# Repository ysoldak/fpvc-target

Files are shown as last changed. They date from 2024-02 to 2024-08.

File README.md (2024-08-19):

# FPVCombat Ground Target and Test Station

Turn your FPV Combat board, sensor and gun to a nice ground target and a reliable test station!  
You'll need [FPV Combat kit](https://fpv-combat.com/) and some other parts, full list below.  
Bottom plate has holes for easy mount on any standard camera tripod.  
Custom firmware for FPVCombat boards in form of `.hex` file can be downloaded from [Releases](https://github.com/ysoldak/fpvc-target/releases).

<table>
<tr><td>
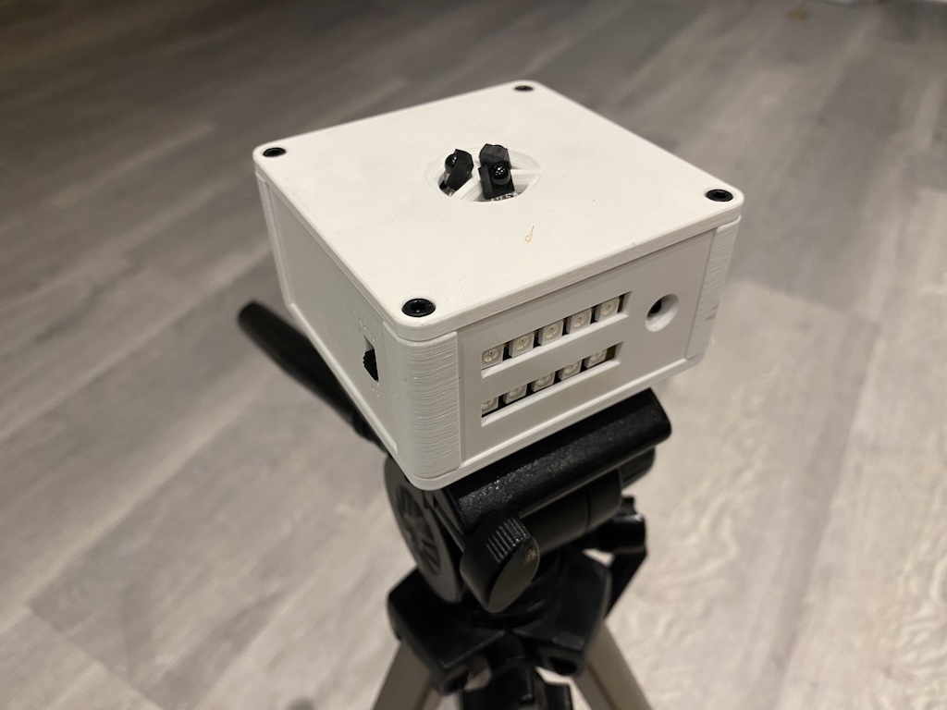
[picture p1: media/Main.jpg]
main

</td><td>
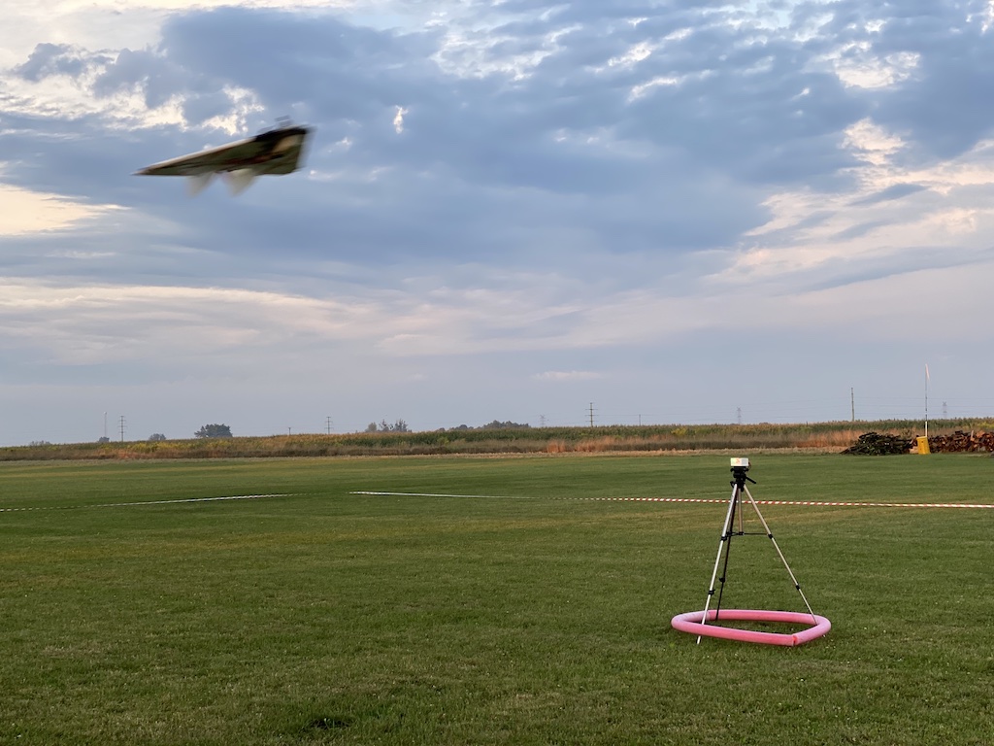
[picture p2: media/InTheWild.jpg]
In the wild

</td></tr>
</table>

## Bill of materials

- FPV Combat kit (board, gun and sensor)  
  https://www.fpv-combat.com/product/fpvcombat_standard/
- HC-12 network board + antenna  
  https://www.amazon.com/HiLetgo-Wireless-Replace-Bluetooth-Antenna/dp/B01MYTE1XR
- Addressible 50x50 RGB LED strip (10 leds), dense  
  https://www.amazon.com/BTF-LIGHTING-WS2812B-Individual-Addressable-Non-waterproof/dp/B01CDTEJR0/
- XT60 connector with mounting brackets to fix with screws or any other regular XT60 connector to fix with hot glue
  https://www.rjxhobby.com/rjxhobby-4pcs-xt60c-m-plug-male-xt60-connector-with-mounting-bracket-black
- Switch for operation mode: TEST or TARGET  
  https://www.amazon.com/Position-Panel-Mount-Vertical-Switch/dp/B07QHCQMNC/
- M3 threaded inserts  (optional)  
  https://cnckitchen.store/products/gewindeeinsatz-threaded-insert-m3-short-100-stk-pcs

## Printing

Prints well in PLA and standard 0.4mm nozzle, no supports needed.
Everything can be printed without supports, even Top and Bottom plates (overhangs are printable w/o supports with a little trick implemented directly into 3D models)

Some parts (Top, Standoff) are available in two variants: basic and for M3 threaded inserts.
Without inserts assembly is faster, with inserts -- nicer and tolerates multiple assemblies/disassemblies.

## Wiring

Wiring of the sensor, gun, HC-12 and addressible 10 RGB strip is straightforward and shall not pose any problems.

### Special wiring
- Solder XT60 male connector to "+" and "-" of the board to power from any standard battery. Best if with extra mounting brackets to screw to the base plate.
- Solder mode switch to SCL pin, shorting SCL and GND enables "TARGET" mode.
- Connect 5V of I2C to any of RC PWM 5V (TRIG, IN or OUT)
- On HW26, sensor shall be connected to `Sensor 1` pins, other sensor pins will not work.
- Trigger gun manually by shorting TRIG and GND (when in TARGET mode) -- simple trigger to shoot at air targets?
- Trigger hit manually by shorting PWM_IN and GND (when in TARGET mode) -- bomb drop detection?

## Flashing

Use XLoader on Windows or avrdude on Mac/Linux to flash included .hex file to the HW25 combat board.
The combat board can be easily restored to original state by flashing official FPV Combat firmware again.

## Operation

Operation modes can be switched at any time with a help of the mode switch, see Wiring.

### Test Mode (default)
"SCL" and "GND" must be disconnected.

Test mode is indicated by a sigle pixel/led moving back and forth.

1. Shoot at the station to start test sequence. First led turns green, means hit received.  
   Check your model's gun and/or sensor of the test station if you can't trigger test sequence.
2. Shortly after the first led, second led lights up either green (means OK) or red (means failure) indicating HC-12 module communication.  
   Check your model's HC-12 module and/or module of the test station if led turns red.
3. Test station then attempts to shoot at your model when both previois steps are green. Turn your model so one of its sensors points at the test station.
   Check your model's sensor and/or test station's gun if hit can't be scored at this stage.

Three leds shall turn green if all 3 tests pass, they then move down one row and moving led appears again indicating the station is ready for a new test session.
In case of any test step fails, respective led (GUN, NETWORK or SENSOR) turns red, state moves one row down and moving led indicates system is ready for a new test session.
Color of the moving led indicates the result of the previous test session (green for success and red for failure).

### Target Mode
"SCL" and "GND" must be connected.

Target mode is indicated by 10 blue leds.

Once a hit is received, a single green led (top/first row) replaces the blue leds.
Once 5 hits received, first led of the bottom row turns green (indicating 5 hits) and first row clears.
10 hits indicated by red led of the second row.
Maximum number of hits indicated: 54 (five red leds of the second row and four green leds of the first row)

When in target mode, trigger gun or hit manually by shorting TRIG and PWM_IN to GND respecfully (since version 1.5.0).  
This feature enables a custom hit detection (bomb drop?) and simple button shooting (ground turret?).

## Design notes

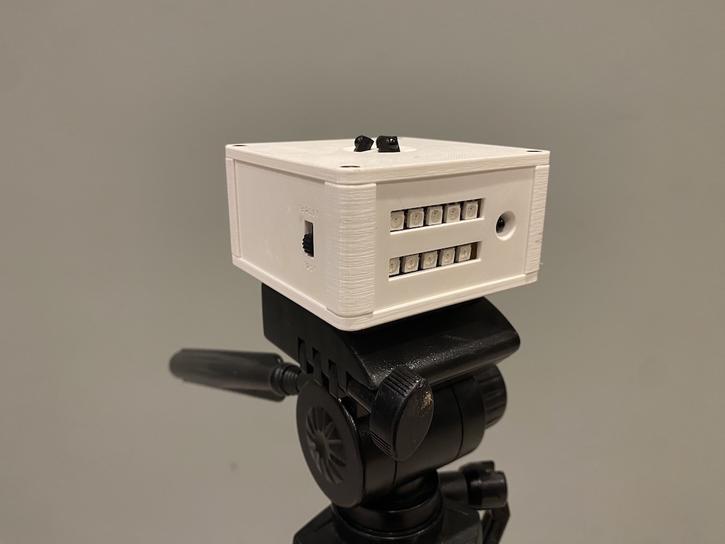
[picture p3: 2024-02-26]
media/Front.jpg

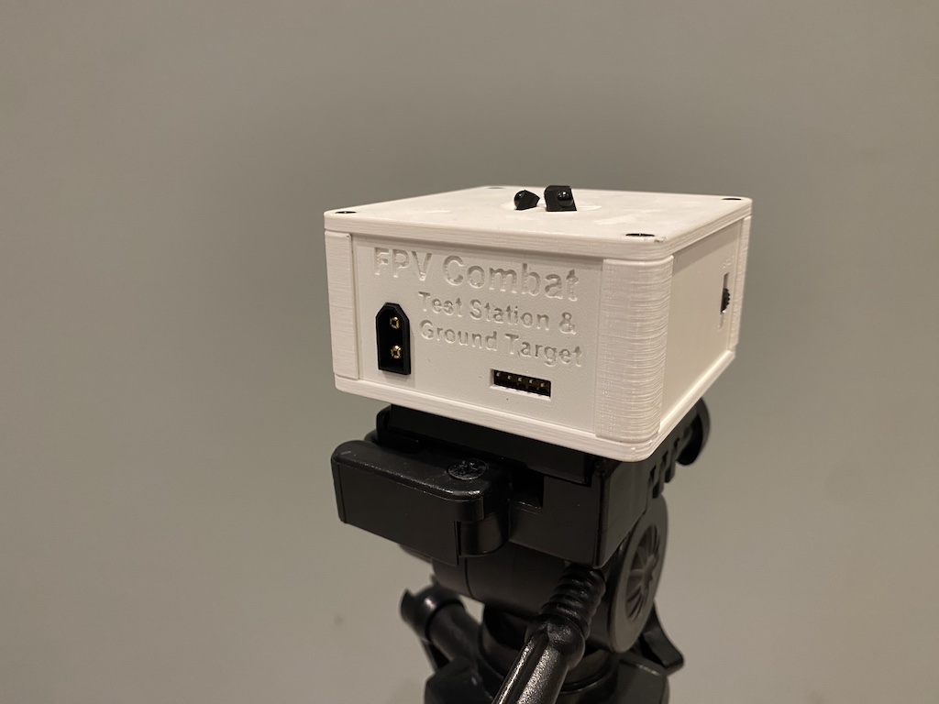
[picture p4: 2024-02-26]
media/Back.jpg

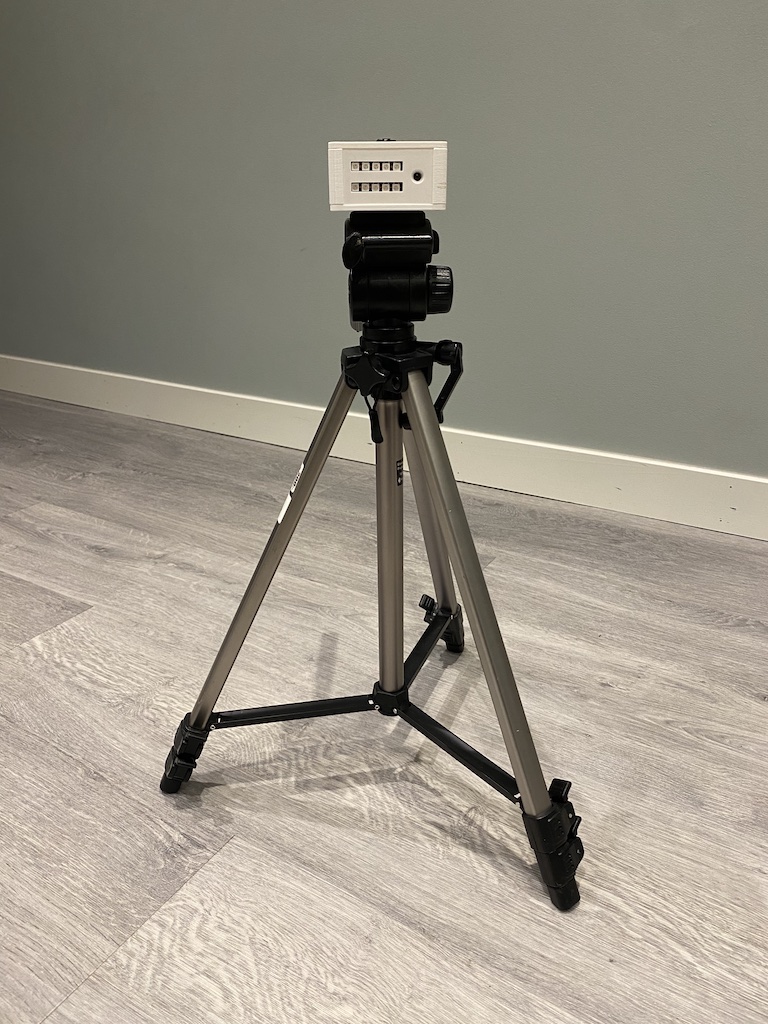
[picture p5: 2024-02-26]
media/Tripod.jpg

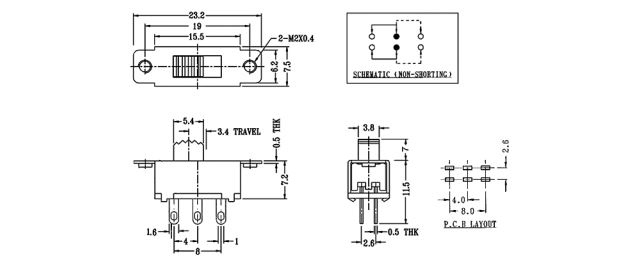
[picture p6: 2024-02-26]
media/Switch2P2T-Dimensions.jpg

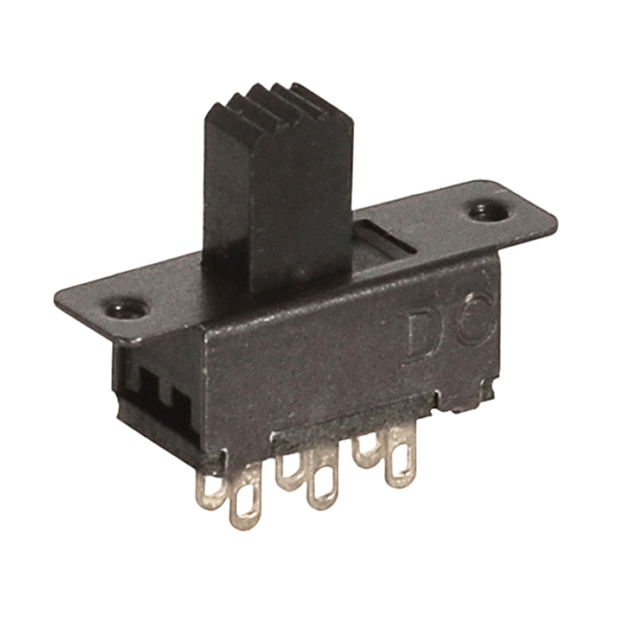
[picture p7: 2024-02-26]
media/Switch2P2T.jpg

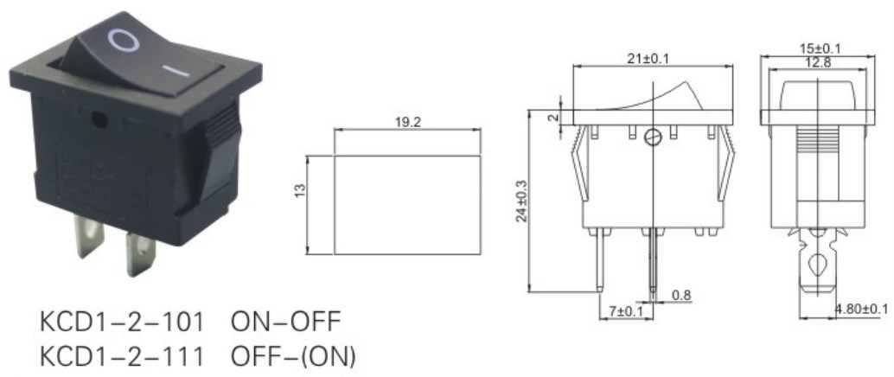
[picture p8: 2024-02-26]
media/SwitchKCD1-101.jpg

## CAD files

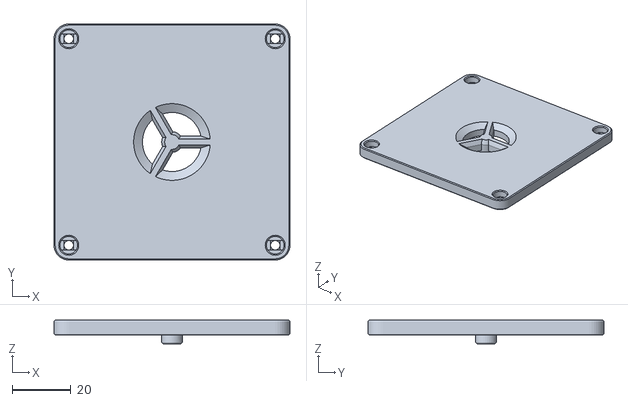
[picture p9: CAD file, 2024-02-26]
case/stl/Top For Inserts.stl
80.0 x 80.0 x 8.00

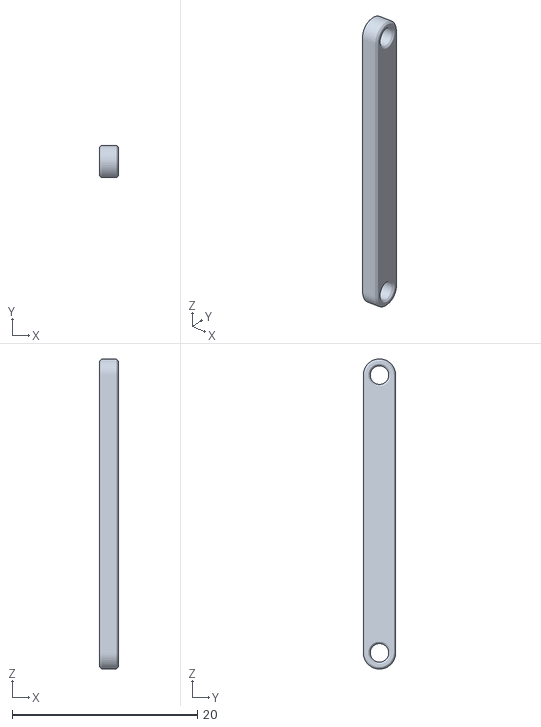
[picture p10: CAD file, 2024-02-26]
case/stl/Front Bracket.stl
2.00 x 3.50 x 33.5

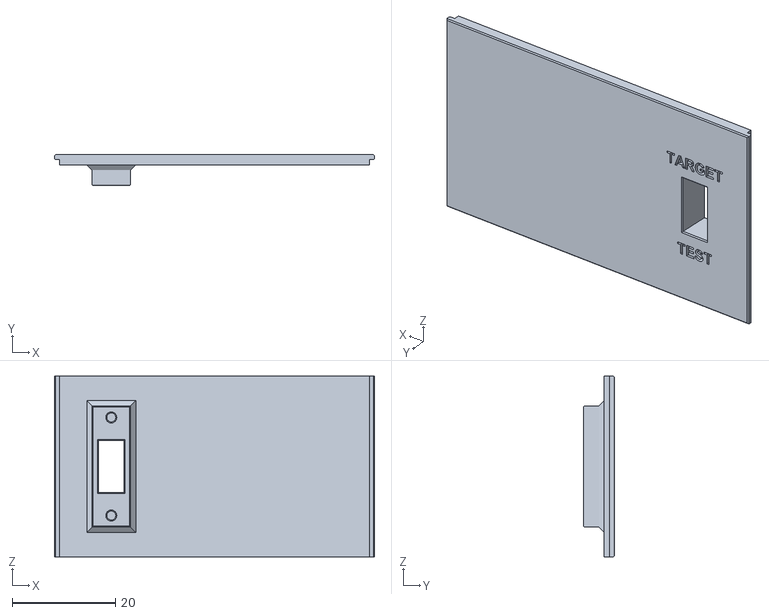
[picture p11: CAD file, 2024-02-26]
case/stl/Switch 2P2T.stl
62.0 x 6.00 x 35.0

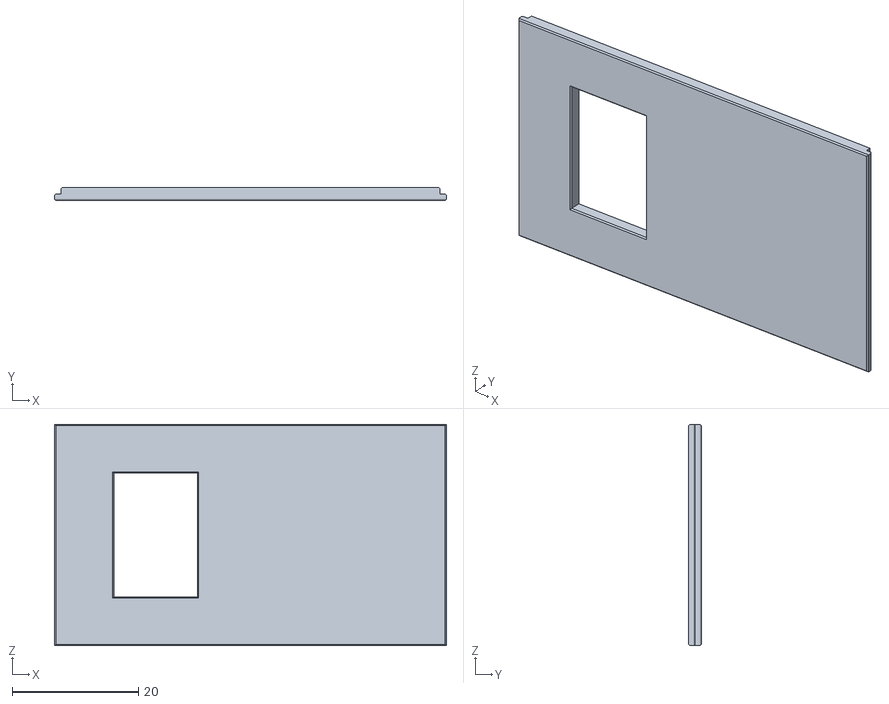
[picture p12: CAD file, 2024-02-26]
case/stl/Switch KCD1-101.stl
62.0 x 2.00 x 35.0

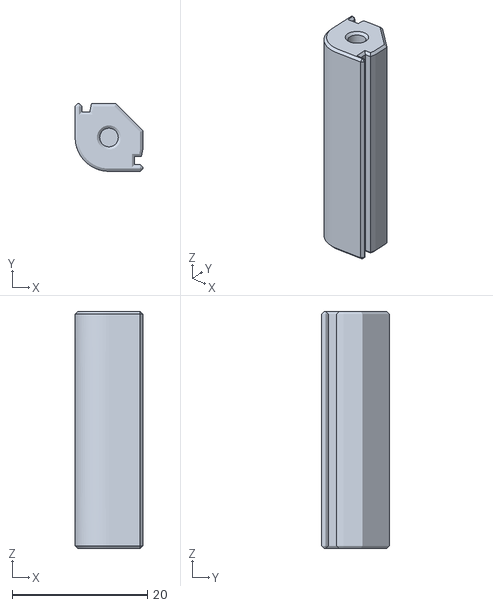
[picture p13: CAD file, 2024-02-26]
case/stl/Standoff.stl
10.0 x 10.0 x 35.0

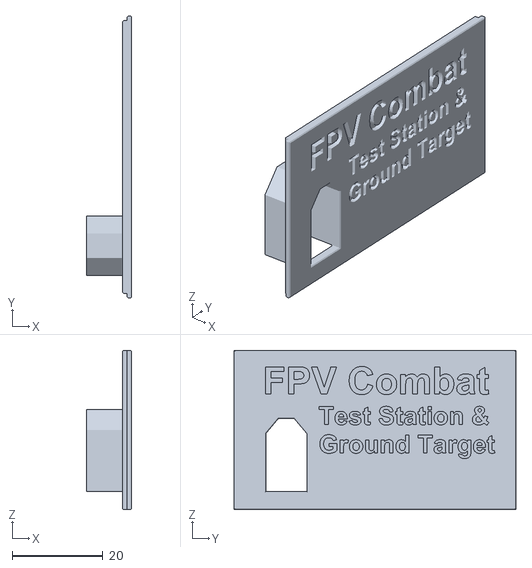
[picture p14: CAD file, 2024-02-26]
case/stl/Back.stl
10.0 x 62.0 x 35.0

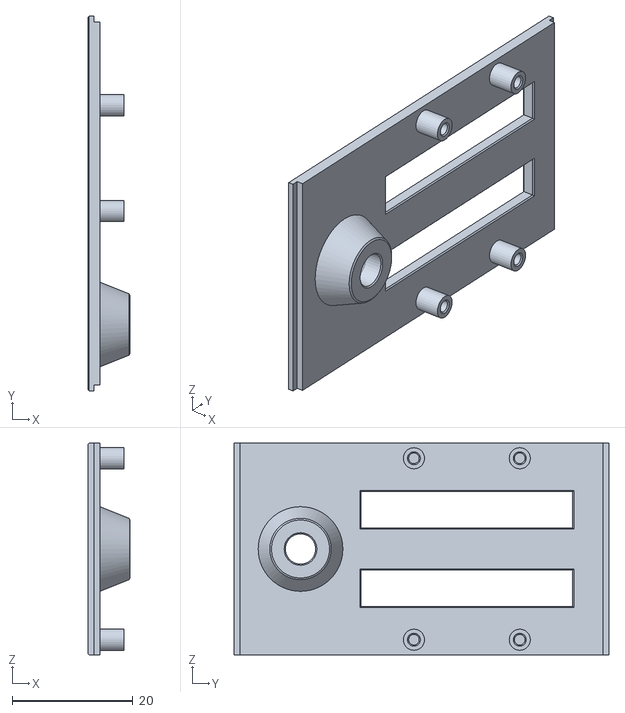
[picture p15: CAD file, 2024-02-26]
case/stl/Front.stl
7.00 x 62.0 x 35.0

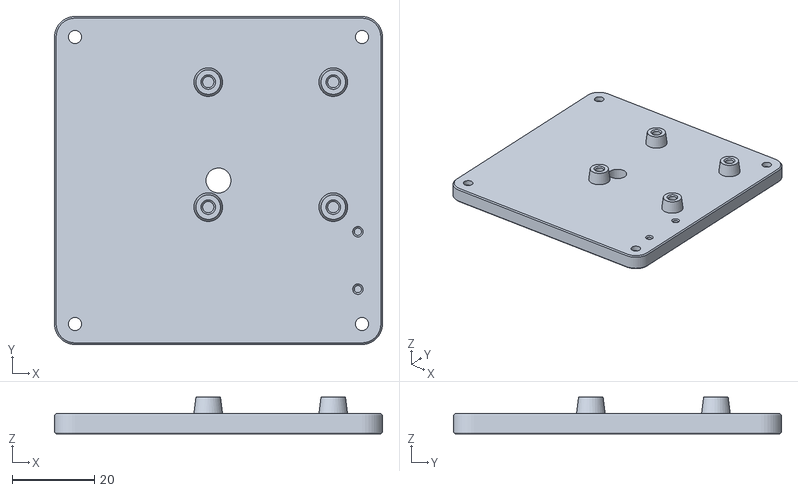
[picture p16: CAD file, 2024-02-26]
case/stl/Bottom.stl
80.0 x 80.0 x 9.00

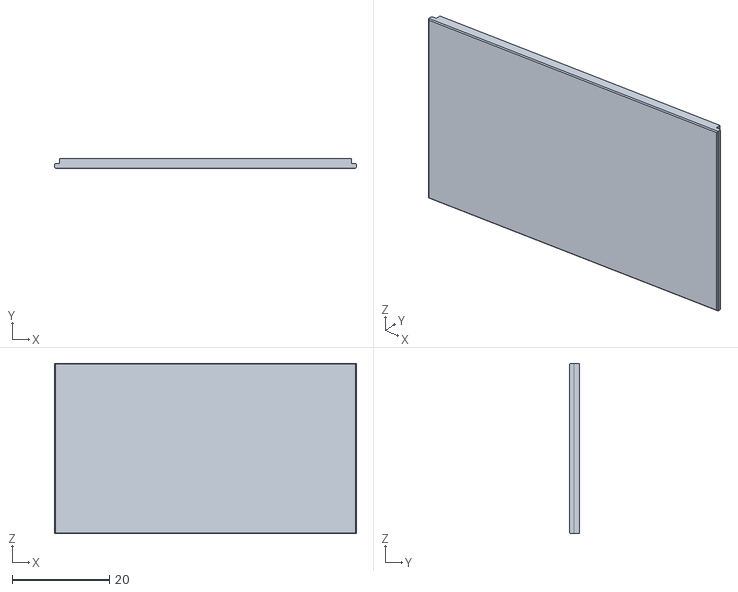
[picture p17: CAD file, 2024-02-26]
case/stl/Blank.stl
62.0 x 2.00 x 35.0

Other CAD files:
case/stl/Switch KCD1-101 Center.stl
case/stl/Standoff For Inserts.stl
case/stl/Top.stl
case/Target.f3d

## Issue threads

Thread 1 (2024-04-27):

New top lid for GND Target case, made for new sensor board.

MrMap, 2024-04-27:
New IR sensorbord is physically different, e.g. no hole for mounting screw.
I made this lid and the new gen board may be fitted using double sided adhesive tape.
There are drill markers for SMA socket connectors for external 433 antenna.

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
[GND Target Top new sensor_proj.zip](https://github.com/ysoldak/fpvc-target/files/15140043/GND.Target.Top.new.sensor_proj.zip)

ysoldak, 2024-05-02:
Thank you! Let me check these new sensors performance and add support for HW2.6 to the ground station. Will incorporate your changes/suggestions in the next release!

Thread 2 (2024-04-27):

Feature request: "High power" hit indication LED support

MrMap, 2024-04-27:
**I would like to attach high Lumen COB-LEDs (daylight visible) to the ground target and have them flash as indication of a target hit.**

On the v2.5 there is a port "P" for similar usage (RGB LED strip driver) but it is not fully operational in current fpvc-target firmware AFAIK.
As for now, one of the output pins are constantly ON (sink to GND), reacting to hits with inverted flashes (short bursts of light-off).
I would like one of the "P" sink pins to react to a hit with a **3 second 5 Hz pulse train, 50% duty cycle**. Or something likewise, useful for the purpose.

The purpose is to provide a immediate, clear and reasonable omnidirectional visual hit response from the ground target - visible both to the pilot and for spectators 50 meters away.

Maybe it can also be used with the test station mode, to verify hits from long distance? (not the priority here...)

ysoldak, 2024-05-02:
Great feature, Tomas! We shall definitely have this.
You solved this already meanwhile, right? Describe here the workaround, perhaps?
